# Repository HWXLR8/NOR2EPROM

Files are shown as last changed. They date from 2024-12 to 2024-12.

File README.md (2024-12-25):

# NOR2EPROM
This is a "simple" drop in replacement for 27C322 UV EPROMs which uses an MX29LV320 (or pin-compatible) NOR flash.
Address lines are shifted from 5V -> 3.3V using 3x 74LVC245 and data lines are shifted from 3.3V -> 5V using 2x 74HCT245.

### Schematic
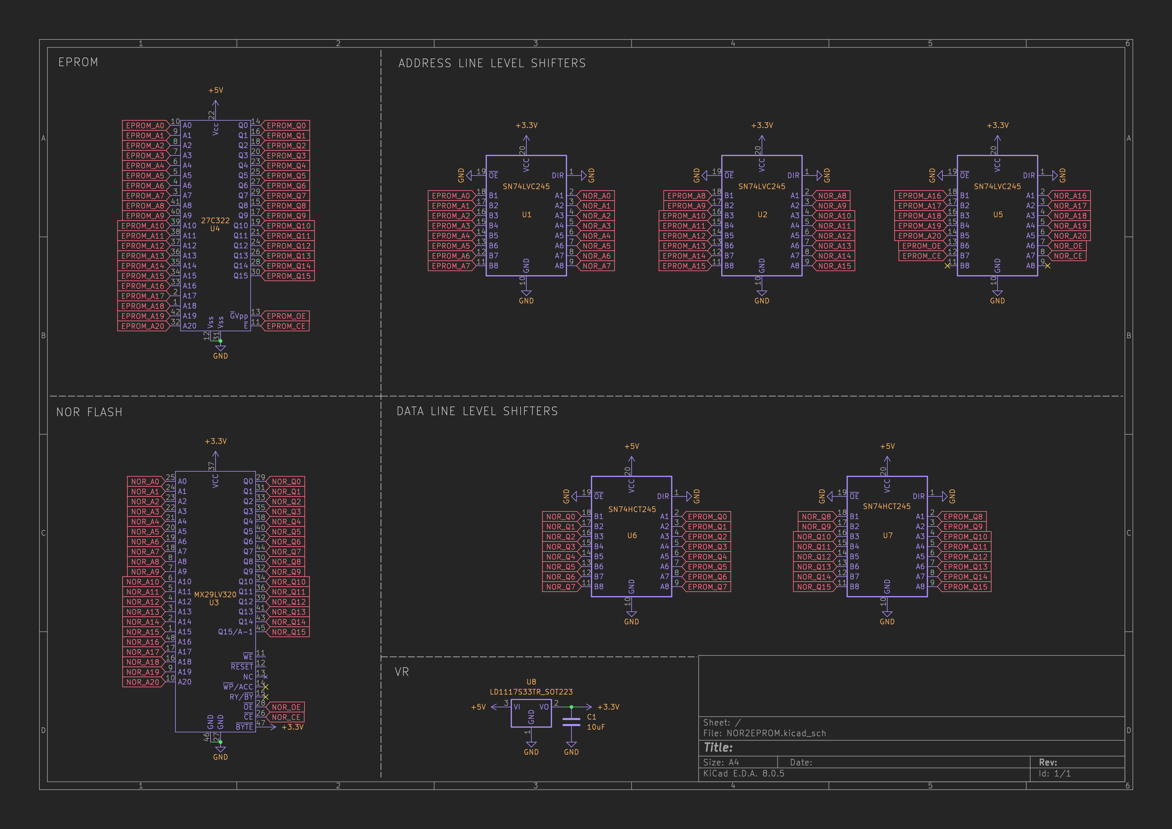
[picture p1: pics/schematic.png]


### PCB
<p float="left">
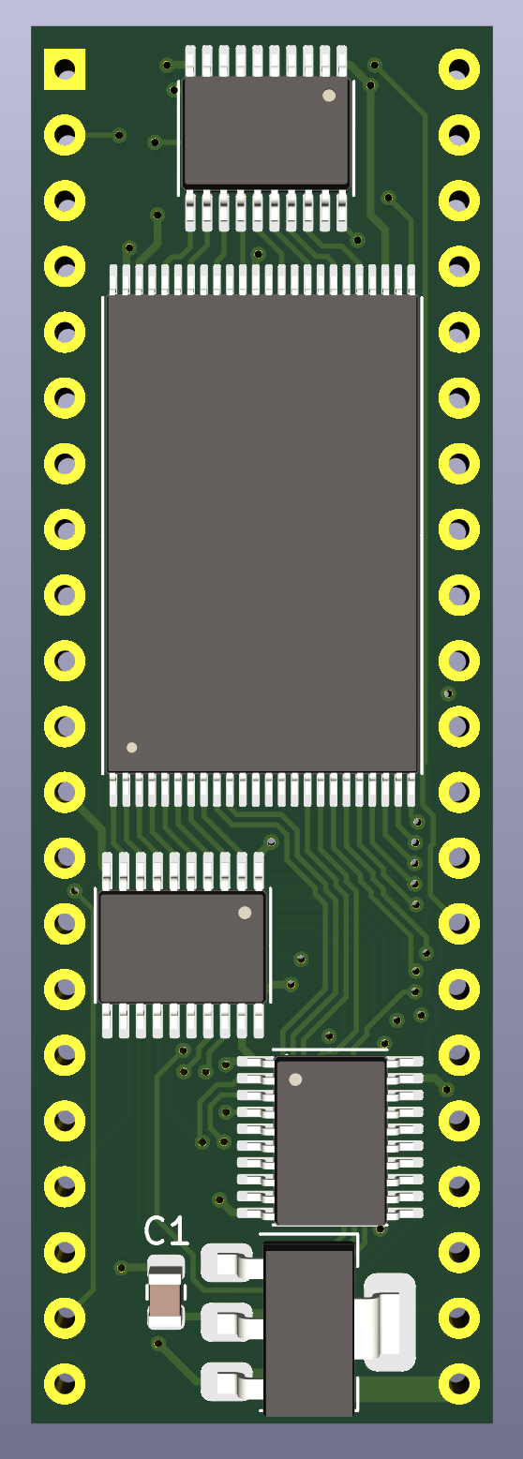
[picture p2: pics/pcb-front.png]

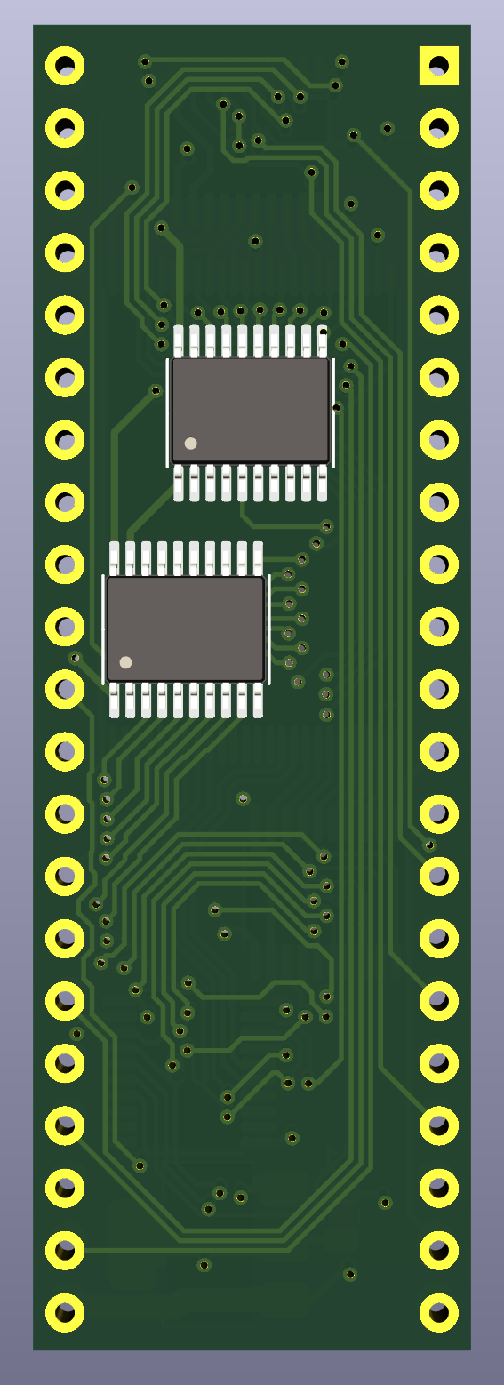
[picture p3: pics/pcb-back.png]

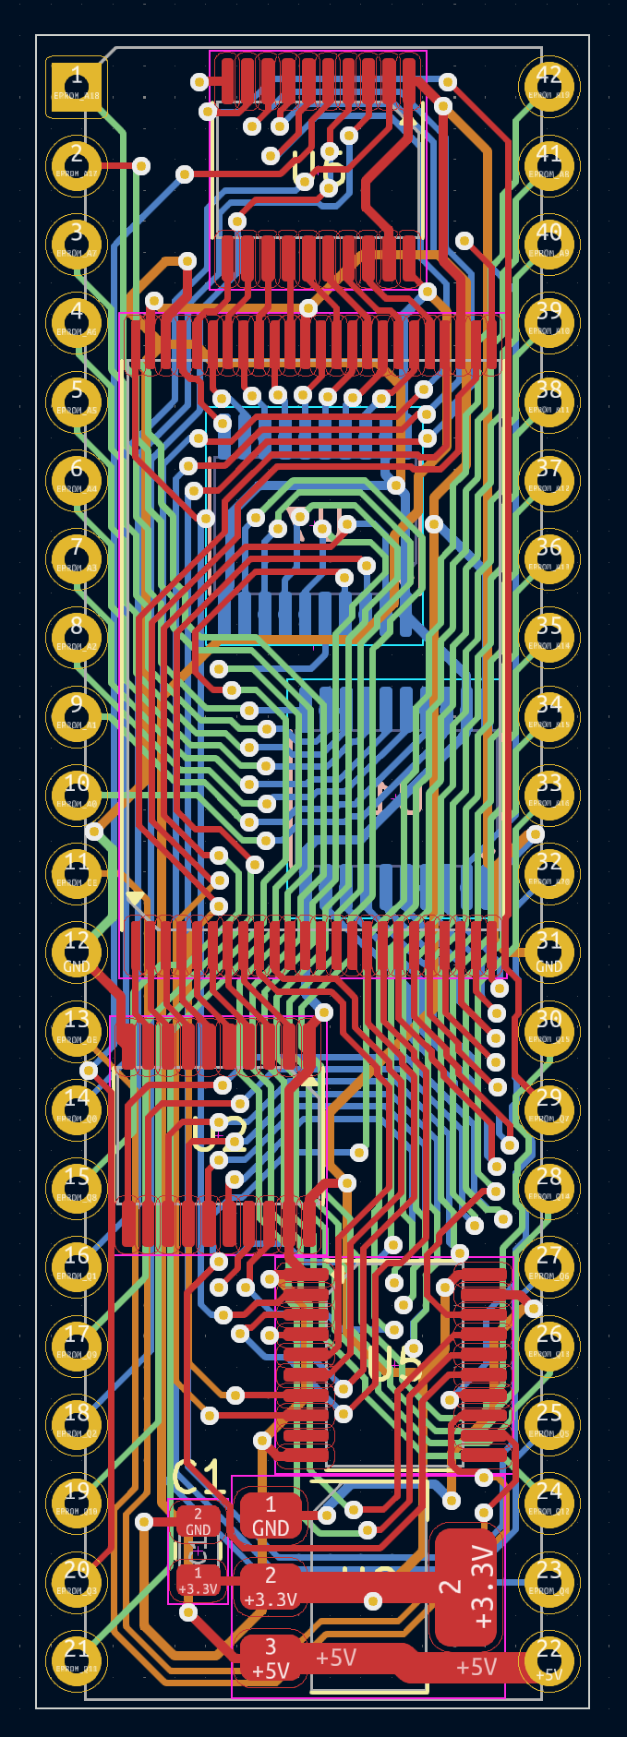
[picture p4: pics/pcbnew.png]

</p>

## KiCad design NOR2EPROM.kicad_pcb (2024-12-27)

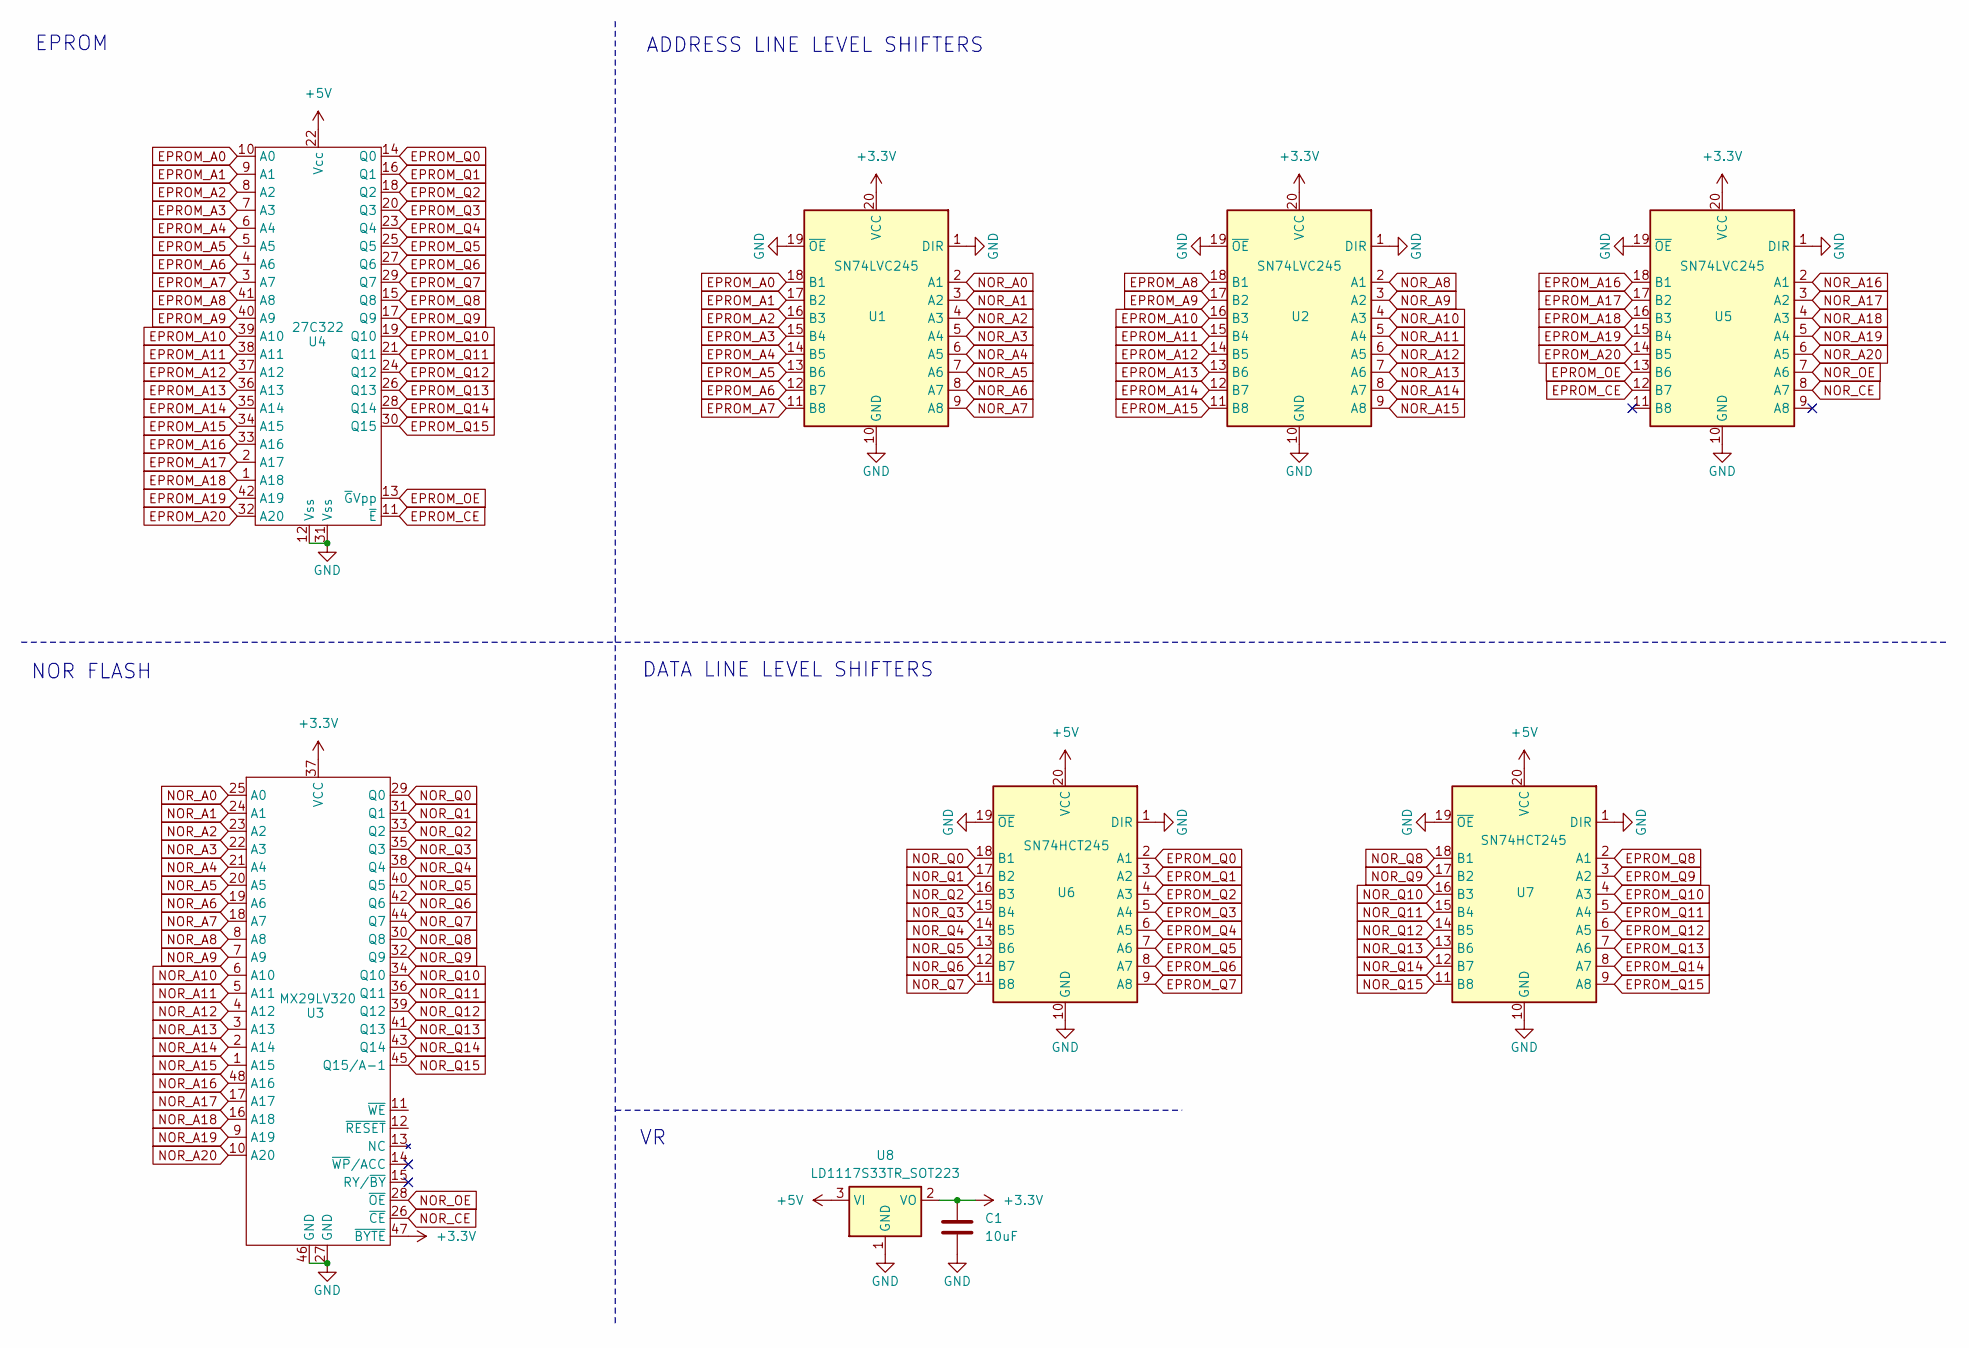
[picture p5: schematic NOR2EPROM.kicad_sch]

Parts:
C1: 10uF; C_0805_2012Metric
U1, U2, U5: SN74LVC245; TSSOP-20_4.4x6.5mm_P0.65mm
U3: MX29LV320; TSOP-I-48_18.4x12mm_P0.5mm
U4: 27C322; DIP-42_W15.24mm
U6, U7: SN74HCT245; TSSOP-20_4.4x6.5mm_P0.65mm
U8: LD1117S33TR_SOT223; SOT-223-3_TabPin2

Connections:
+3.3V: C1.1, U1.20 (VCC), U2.20 (VCC), U3.37 (VCC), U3.47 (~BYTE), U5.20 (VCC), U8.2 (VO)
+5V: U4.22 (Vcc), U6.20 (VCC), U7.20 (VCC), U8.3 (VI)
EPROM_A0: U1.18 (B1), U4.10 (A0)
EPROM_A1: U1.17 (B2), U4.9 (A1)
EPROM_A2: U1.16 (B3), U4.8 (A2)
EPROM_A3: U1.15 (B4), U4.7 (A3)
EPROM_A4: U1.14 (B5), U4.6 (A4)
EPROM_A5: U1.13 (B6), U4.5 (A5)
EPROM_A6: U1.12 (B7), U4.4 (A6)
EPROM_A7: U1.11 (B8), U4.3 (A7)
EPROM_A8: U2.18 (B1), U4.41 (A8)
EPROM_A9: U2.17 (B2), U4.40 (A9)
EPROM_A10: U2.16 (B3), U4.39 (A10)
EPROM_A11: U2.15 (B4), U4.38 (A11)
EPROM_A12: U2.14 (B5), U4.37 (A12)
EPROM_A13: U2.13 (B6), U4.36 (A13)
EPROM_A14: U2.12 (B7), U4.35 (A14)
EPROM_A15: U2.11 (B8), U4.34 (A15)
EPROM_A16: U4.33 (A16), U5.18 (B1)
EPROM_A17: U4.2 (A17), U5.17 (B2)
EPROM_A18: U4.1 (A18), U5.16 (B3)
EPROM_A19: U4.42 (A19), U5.15 (B4)
EPROM_A20: U4.32 (A20), U5.14 (B5)
EPROM_CE: U4.11 (~E), U5.12 (B7)
EPROM_OE: U4.13 (~GVpp), U5.13 (B6)
EPROM_Q0: U4.14 (Q0), U6.2 (A1)
EPROM_Q1: U4.16 (Q1), U6.3 (A2)
EPROM_Q2: U4.18 (Q2), U6.4 (A3)
EPROM_Q3: U4.20 (Q3), U6.5 (A4)
EPROM_Q4: U4.23 (Q4), U6.6 (A5)
EPROM_Q5: U4.25 (Q5), U6.7 (A6)
EPROM_Q6: U4.27 (Q6), U6.8 (A7)
EPROM_Q7: U4.29 (Q7), U6.9 (A8)
EPROM_Q8: U4.15 (Q8), U7.2 (A1)
EPROM_Q9: U4.17 (Q9), U7.3 (A2)
EPROM_Q10: U4.19 (Q10), U7.4 (A3)
EPROM_Q11: U4.21 (Q11), U7.5 (A4)
EPROM_Q12: U4.24 (Q12), U7.6 (A5)
EPROM_Q13: U4.26 (Q13), U7.7 (A6)
EPROM_Q14: U4.28 (Q14), U7.8 (A7)
EPROM_Q15: U4.30 (Q15), U7.9 (A8)
GND: C1.2, U1.1 (DIR), U1.10 (GND), U1.19 (~OE), U2.1 (DIR), U2.10 (GND), U2.19 (~OE), U3.27 (GND), U3.46 (GND), U4.12 (Vss), U4.31 (Vss), U5.1 (DIR), U5.10 (GND), U5.19 (~OE), U6.1 (DIR), U6.10 (GND), U6.19 (~OE), U7.1 (DIR), U7.10 (GND), U7.19 (~OE), U8.1 (GND)
NOR_A0: U1.2 (A1), U3.25 (A0)
NOR_A1: U1.3 (A2), U3.24 (A1)
NOR_A2: U1.4 (A3), U3.23 (A2)
NOR_A3: U1.5 (A4), U3.22 (A3)
NOR_A4: U1.6 (A5), U3.21 (A4)
NOR_A5: U1.7 (A6), U3.20 (A5)
NOR_A6: U1.8 (A7), U3.19 (A6)
NOR_A7: U1.9 (A8), U3.18 (A7)
NOR_A8: U2.2 (A1), U3.8 (A8)
NOR_A9: U2.3 (A2), U3.7 (A9)
NOR_A10: U2.4 (A3), U3.6 (A10)
NOR_A11: U2.5 (A4), U3.5 (A11)
NOR_A12: U2.6 (A5), U3.4 (A12)
NOR_A13: U2.7 (A6), U3.3 (A13)
NOR_A14: U2.8 (A7), U3.2 (A14)
NOR_A15: U2.9 (A8), U3.1 (A15)
NOR_A16: U3.48 (A16), U5.2 (A1)
NOR_A17: U3.17 (A17), U5.3 (A2)
NOR_A18: U3.16 (A18), U5.4 (A3)
NOR_A19: U3.9 (A19), U5.5 (A4)
NOR_A20: U3.10 (A20), U5.6 (A5)
NOR_CE: U3.26 (~CE), U5.8 (A7)
NOR_OE: U3.28 (~OE), U5.7 (A6)
NOR_Q0: U3.29 (Q0), U6.18 (B1)
NOR_Q1: U3.31 (Q1), U6.17 (B2)
NOR_Q2: U3.33 (Q2), U6.16 (B3)
NOR_Q3: U3.35 (Q3), U6.15 (B4)
NOR_Q4: U3.38 (Q4), U6.14 (B5)
NOR_Q5: U3.40 (Q5), U6.13 (B6)
NOR_Q6: U3.42 (Q6), U6.12 (B7)
NOR_Q7: U3.44 (Q7), U6.11 (B8)
NOR_Q8: U3.30 (Q8), U7.18 (B1)
NOR_Q9: U3.32 (Q9), U7.17 (B2)
NOR_Q10: U3.34 (Q10), U7.16 (B3)
NOR_Q11: U3.36 (Q11), U7.15 (B4)
NOR_Q12: U3.39 (Q12), U7.14 (B5)
NOR_Q13: U3.41 (Q13), U7.13 (B6)
NOR_Q14: U3.43 (Q14), U7.12 (B7)
NOR_Q15: U3.45 (Q15/A-1), U7.11 (B8)

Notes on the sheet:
EPROM
ADDRESS LINE LEVEL SHIFTERS
NOR FLASH
DATA LINE LEVEL SHIFTERS

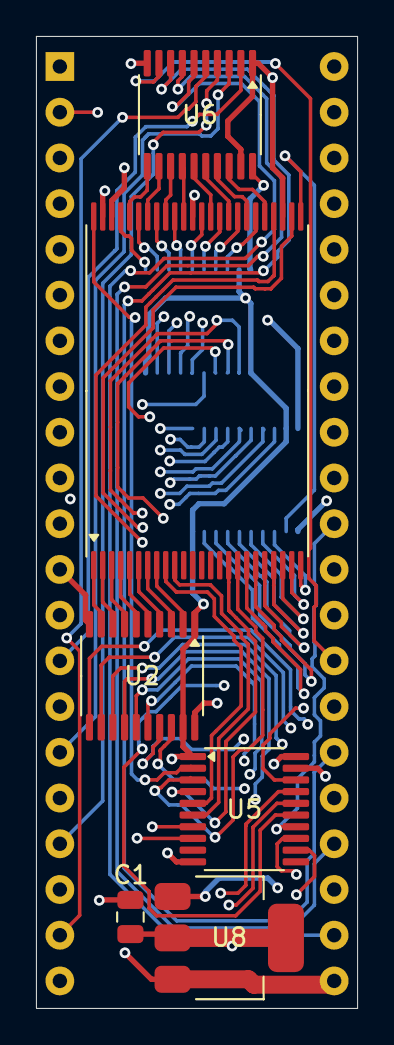
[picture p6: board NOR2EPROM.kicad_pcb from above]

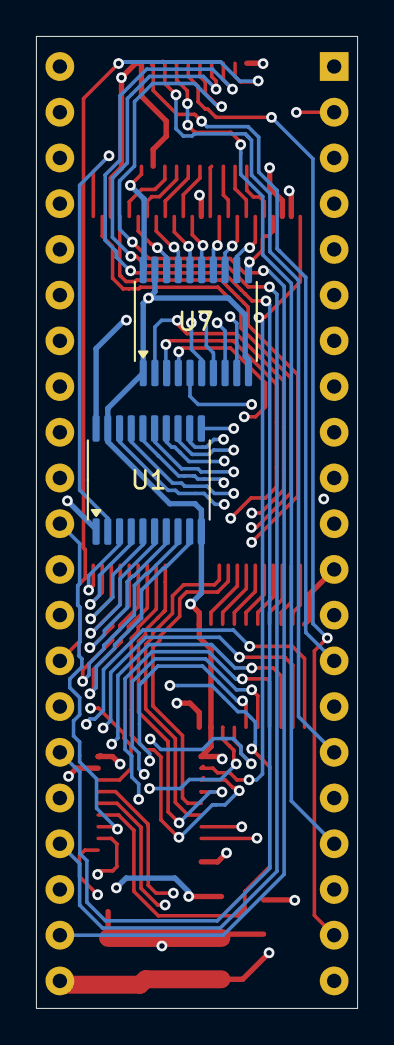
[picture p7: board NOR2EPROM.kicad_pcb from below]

Board: 4 copper layers, 17.8 x 54.0 mm, 9 parts (2 on the bottom side), 81 nets.

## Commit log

2024-12-20 finalize alpha schematic done
    [NOR2EPROM.kicad_sch]
2024-12-21 add output cap, position components before routing
    [NOR2EPROM.kicad_pcb, NOR2EPROM.kicad_sch]
2024-12-21 routing checkpoint
    [NOR2EPROM.kicad_pcb]
2024-12-24 finished routing
    [NOR2EPROM.kicad_pcb]
2024-12-24 fix drc errors
    [NOR2EPROM.kicad_pcb]
2024-12-25 clean up schematic
    [NOR2EPROM.kicad_sch]
2024-12-25 add pcb pics
2024-12-27 level shift OE and CE lines
    [NOR2EPROM.kicad_pcb, NOR2EPROM.kicad_sch]
